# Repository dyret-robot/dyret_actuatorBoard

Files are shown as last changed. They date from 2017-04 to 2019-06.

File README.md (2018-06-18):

# `dyret_actuatorBoard`
   

This repository contains the code and PCB design of the `dyret_actuatorBoard`.

## Documentation
For further documentation check out the
[wiki](https://github.com/dyret-robot/dyret_documentation/wiki).

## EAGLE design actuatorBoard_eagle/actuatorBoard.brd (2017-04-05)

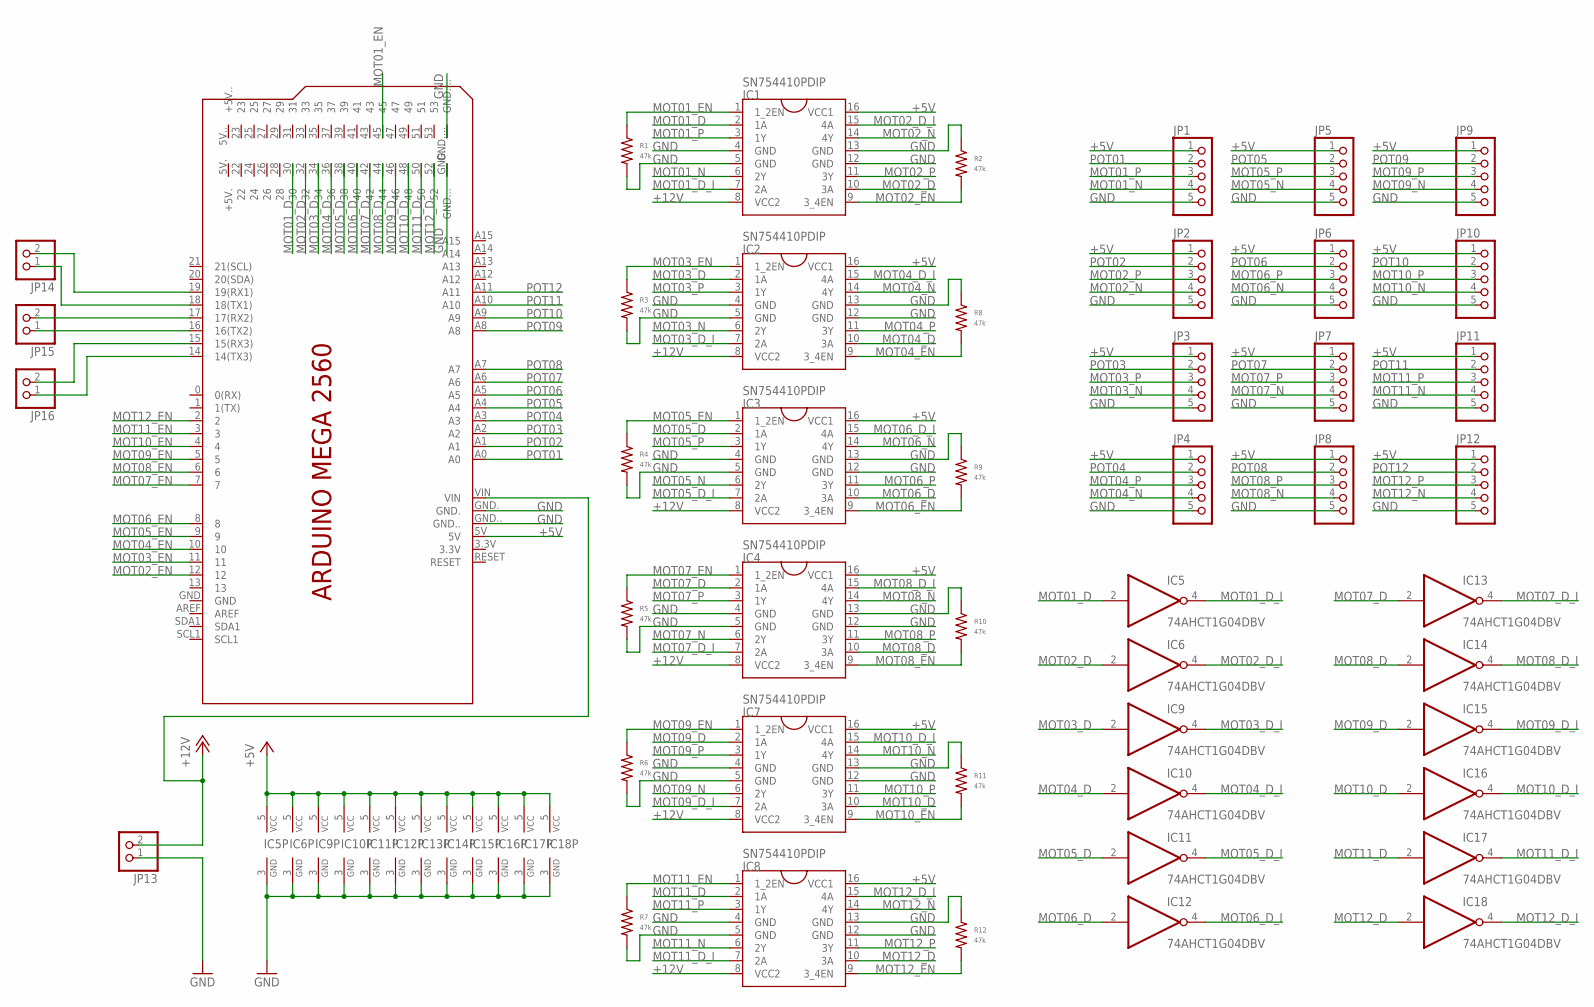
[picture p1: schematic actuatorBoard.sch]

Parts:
IC1, IC2, IC3, IC4, IC7, IC8: SN754410PDIP; DIL16
IC5, IC6, IC9, IC10, IC11, IC12, IC13, IC14, IC15, IC16, IC17, IC18: 74AHCT1G04DBV; SOT23-5
JP1, JP2, JP3, JP4, JP5, JP6, JP7, JP8, JP9, JP10, JP11, JP12: PINHD-1X5; 1X05
JP13, JP14, JP15, JP16: PINHD-1X2; 1X02
PCB1: ARDUINO_MEGA2560
R1, R2, R3, R4, R5, R6, R7, R8, R9, R10, R11, R12: 47k; R0603

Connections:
+5V: IC1.16 (VCC1), IC2.16 (VCC1), IC3.16 (VCC1), IC4.16 (VCC1), IC5.5 (VCC), IC6.5 (VCC), IC7.16 (VCC1), IC8.16 (VCC1), IC9.5 (VCC), IC10.5 (VCC), IC11.5 (VCC), IC12.5 (VCC), IC13.5 (VCC), IC14.5 (VCC), IC15.5 (VCC), IC16.5 (VCC), IC17.5 (VCC), IC18.5 (VCC), JP1.1, JP2.1, JP3.1, JP4.1, JP5.1, JP6.1, JP7.1, JP8.1, JP9.1, JP10.1, JP11.1, JP12.1, PCB1.5V
+12V: IC1.8 (VCC2), IC2.8 (VCC2), IC3.8 (VCC2), IC4.8 (VCC2), IC7.8 (VCC2), IC8.8 (VCC2), JP13.2, PCB1.VIN
GND: IC1.4 (GND), IC1.5 (GND), IC1.12 (GND), IC1.13 (GND), IC2.4 (GND), IC2.5 (GND), IC2.12 (GND), IC2.13 (GND), IC3.4 (GND), IC3.5 (GND), IC3.12 (GND), IC3.13 (GND), IC4.4 (GND), IC4.5 (GND), IC4.12 (GND), IC4.13 (GND), IC5.3 (GND), IC6.3 (GND), IC7.4 (GND), IC7.5 (GND), IC7.12 (GND), IC7.13 (GND), IC8.4 (GND), IC8.5 (GND), IC8.12 (GND), IC8.13 (GND), IC9.3 (GND), IC10.3 (GND), IC11.3 (GND), IC12.3 (GND), IC13.3 (GND), IC14.3 (GND), IC15.3 (GND), IC16.3 (GND), IC17.3 (GND), IC18.3 (GND), JP1.5, JP2.5, JP3.5, JP4.5, JP5.5, JP6.5, JP7.5, JP8.5, JP9.5, JP10.5, JP11.5, JP12.5, JP13.1, PCB1.GND., PCB1.GND.., PCB1.GND..., PCB1.GND...., R1.P$2, R2.P$1, R3.P$2, R4.P$2, R5.P$2, R6.P$2, R7.P$2, R8.P$1, R9.P$1, R10.P$1, R11.P$1, R12.P$1
MOT01_D: IC1.2 (1A), IC5.2 (I), PCB1.30
MOT01_D_I: IC1.7 (2A), IC5.4 (O)
MOT01_EN: IC1.1 (1_2EN), PCB1.45, R1.P$1
MOT01_N: IC1.6 (2Y), JP1.4
MOT01_P: IC1.3 (1Y), JP1.3
MOT02_D: IC1.10 (3A), IC6.2 (I), PCB1.32
MOT02_D_I: IC1.15 (4A), IC6.4 (O)
MOT02_EN: IC1.9 (3_4EN), PCB1.12, R2.P$2
MOT02_N: IC1.14 (4Y), JP2.4
MOT02_P: IC1.11 (3Y), JP2.3
MOT03_D: IC2.2 (1A), IC9.2 (I), PCB1.34
MOT03_D_I: IC2.7 (2A), IC9.4 (O)
MOT03_EN: IC2.1 (1_2EN), PCB1.11, R3.P$1
MOT03_N: IC2.6 (2Y), JP3.4
MOT03_P: IC2.3 (1Y), JP3.3
MOT04_D: IC2.10 (3A), IC10.2 (I), PCB1.36
MOT04_D_I: IC2.15 (4A), IC10.4 (O)
MOT04_EN: IC2.9 (3_4EN), PCB1.10, R8.P$2
MOT04_N: IC2.14 (4Y), JP4.4
MOT04_P: IC2.11 (3Y), JP4.3
MOT05_D: IC3.2 (1A), IC11.2 (I), PCB1.38
MOT05_D_I: IC3.7 (2A), IC11.4 (O)
MOT05_EN: IC3.1 (1_2EN), PCB1.9, R4.P$1
MOT05_N: IC3.6 (2Y), JP5.4
MOT05_P: IC3.3 (1Y), JP5.3
MOT06_D: IC3.10 (3A), IC12.2 (I), PCB1.40
MOT06_D_I: IC3.15 (4A), IC12.4 (O)
MOT06_EN: IC3.9 (3_4EN), PCB1.8, R9.P$2
MOT06_N: IC3.14 (4Y), JP6.4
MOT06_P: IC3.11 (3Y), JP6.3
MOT07_D: IC4.2 (1A), IC13.2 (I), PCB1.42
MOT07_D_I: IC4.7 (2A), IC13.4 (O)
MOT07_EN: IC4.1 (1_2EN), PCB1.7, R5.P$1
MOT07_N: IC4.6 (2Y), JP7.4
MOT07_P: IC4.3 (1Y), JP7.3
MOT08_D: IC4.10 (3A), IC14.2 (I), PCB1.44
MOT08_D_I: IC4.15 (4A), IC14.4 (O)
MOT08_EN: IC4.9 (3_4EN), PCB1.6, R10.P$2
MOT08_N: IC4.14 (4Y), JP8.4
MOT08_P: IC4.11 (3Y), JP8.3
MOT09_D: IC7.2 (1A), IC15.2 (I), PCB1.46
MOT09_D_I: IC7.7 (2A), IC15.4 (O)
MOT09_EN: IC7.1 (1_2EN), PCB1.5, R6.P$1
MOT09_N: IC7.6 (2Y), JP9.4
MOT09_P: IC7.3 (1Y), JP9.3
MOT10_D: IC7.10 (3A), IC16.2 (I), PCB1.48
MOT10_D_I: IC7.15 (4A), IC16.4 (O)
MOT10_EN: IC7.9 (3_4EN), PCB1.4, R11.P$2
MOT10_N: IC7.14 (4Y), JP10.4
MOT10_P: IC7.11 (3Y), JP10.3
MOT11_D: IC8.2 (1A), IC17.2 (I), PCB1.50
MOT11_D_I: IC8.7 (2A), IC17.4 (O)
MOT11_EN: IC8.1 (1_2EN), PCB1.3, R7.P$1
MOT11_N: IC8.6 (2Y), JP11.4
MOT11_P: IC8.3 (1Y), JP11.3
MOT12_D: IC8.10 (3A), IC18.2 (I), PCB1.52
MOT12_D_I: IC8.15 (4A), IC18.4 (O)
MOT12_EN: IC8.9 (3_4EN), PCB1.2, R12.P$2
MOT12_N: IC8.14 (4Y), JP12.4
MOT12_P: IC8.11 (3Y), JP12.3
unnamed: JP15.2, PCB1.17 (17(RX2))
unnamed: JP15.1, PCB1.16 (16(TX2))
unnamed: JP14.1, PCB1.18 (18(TX1))
unnamed: JP14.2, PCB1.19 (19(RX1))
unnamed: JP16.2, PCB1.15 (15(RX3))
unnamed: JP16.1, PCB1.14 (14(TX3))
POT01: JP1.2, PCB1.A0
POT02: JP2.2, PCB1.A1
POT03: JP3.2, PCB1.A2
POT04: JP4.2, PCB1.A3
POT05: JP5.2, PCB1.A4
POT06: JP6.2, PCB1.A5
POT07: JP7.2, PCB1.A6
POT08: JP8.2, PCB1.A7
POT09: JP9.2, PCB1.A8
POT10: JP10.2, PCB1.A9
POT11: JP11.2, PCB1.A10
POT12: JP12.2, PCB1.A11

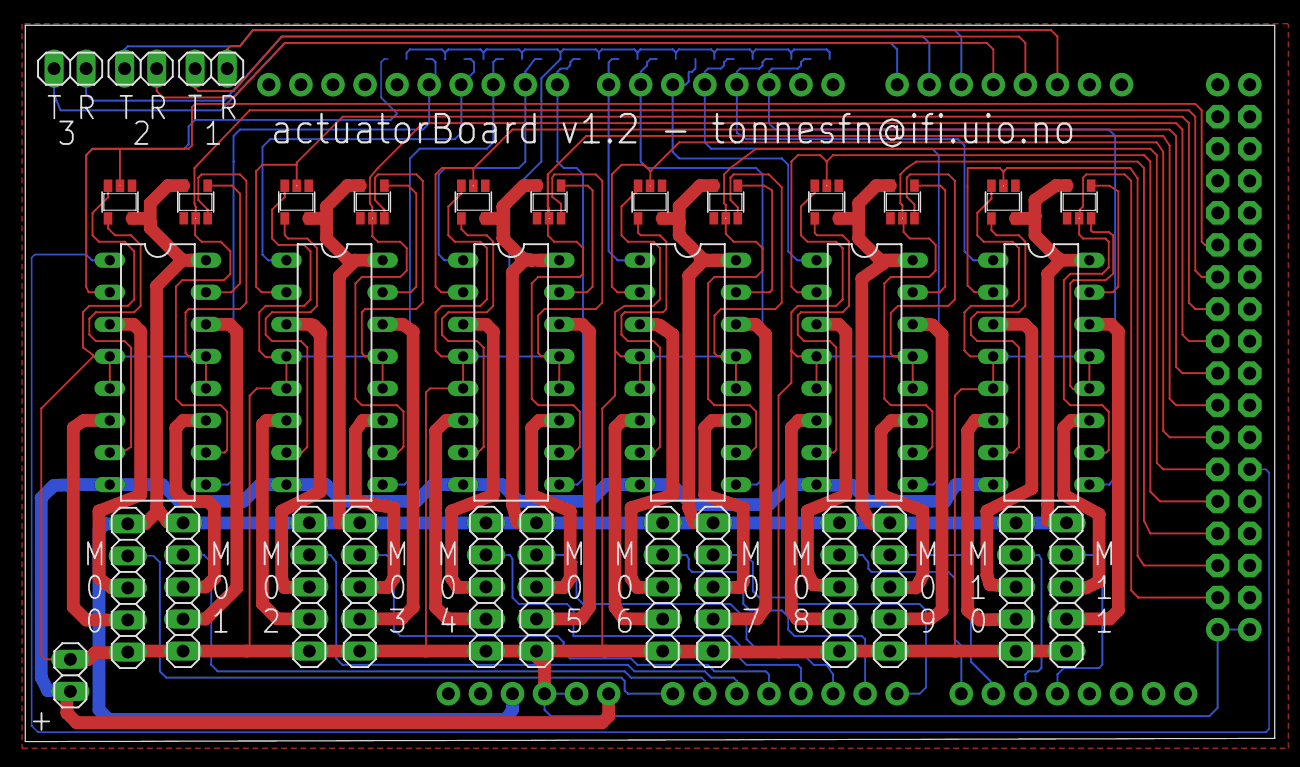
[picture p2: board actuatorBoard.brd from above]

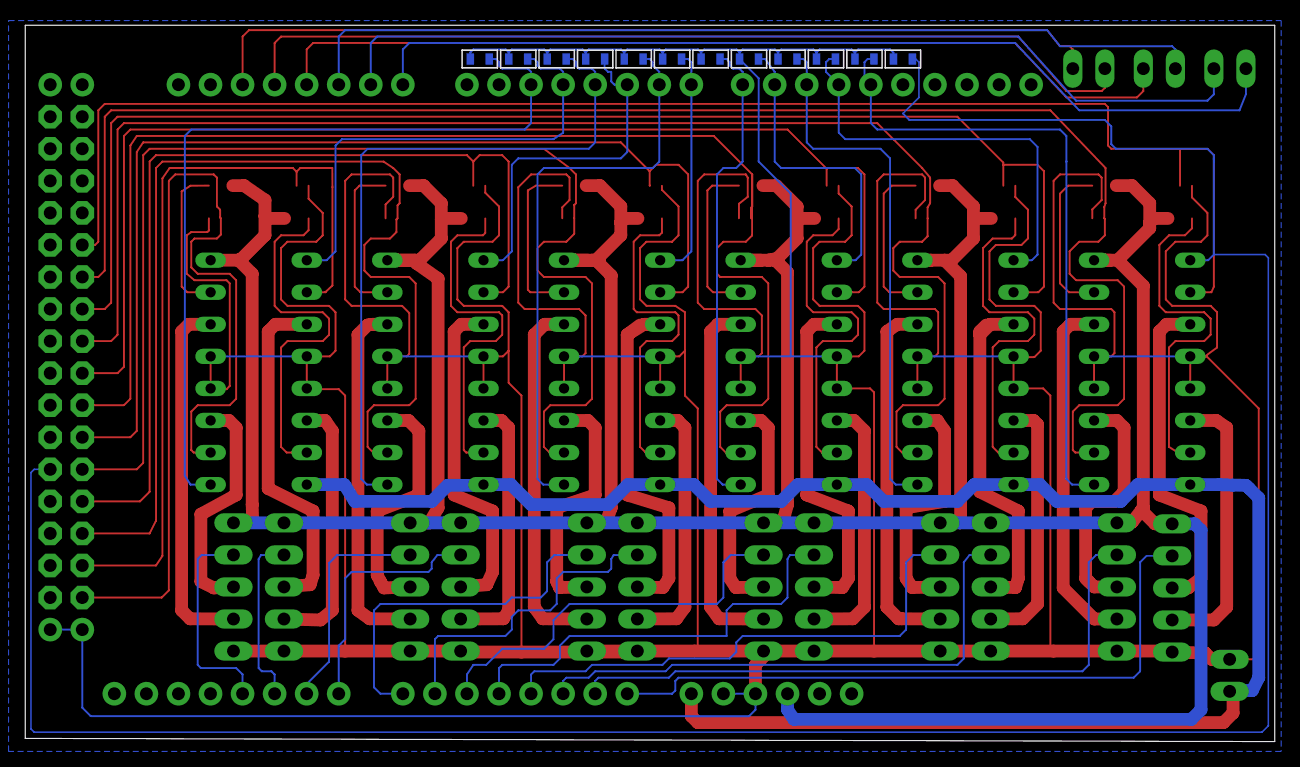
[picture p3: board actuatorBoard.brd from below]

Board: 2 copper layers, 99.0 x 56.8 mm, 47 parts (12 on the bottom side), 81 nets.

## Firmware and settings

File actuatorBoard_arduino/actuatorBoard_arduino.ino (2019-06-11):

#include <ros.h>
#include <dyret_hardware/ActuatorBoardCommand.h>
#include <dyret_hardware/ActuatorBoardState.h>
#include <std_msgs/String.h>

const int actuatorEnablePins[]    = {11, 10,  7,  6,  5,  4,  3,  2};
const int actuatorDirectionPins[] = {34, 36, 42, 44, 46, 48, 50, 52};
const int limitSwitchInputPins[]  = {25, 29, 33, 37, 41, 45, 49, 53};
const int limitSwitchOutputPins[] = {23, 27, 31, 35, 39, 43, 47, 51};
const int encoderInputPins[]      = { 2,  3,  6,  7,  8,  9, 10, 11};

const int pValue = 500;

unsigned long sendMessagePreviousms = 0;
const int sendMessageIntervalms = 100; // 10hz
unsigned long motorControlPreviousms = 0;
const int motorControlIntervalms = 10; // 100hz
unsigned long errorDetectionPreviousms = 0;
const int errorDetectionIntervalms = 2000; // 2hz

const int femurLengthLimit = 50;
const int tibiaLengthLimit = 95;

bool initiated[8];

bool commandReceived[8];

float actuatorGoal[8];

float lastPos[8]; // Last recorded position, used to detect stuck motors or faulty encoders
bool currentlyRunning[8];
bool motorError[8];
float currentPos[8]; // Current position in MM

int lastMeasurement[8];
int turnCounter[8];

unsigned motorPwm[8];

int zeroOffset[8]; // Contains the offset when zero

ros::NodeHandle nh;

dyret_hardware::ActuatorBoardState stateMessage;
ros::Publisher statePub("dyret/actuator_board/state", &stateMessage);

void messageCb(const dyret_hardware::ActuatorBoardCommand& msg);
ros::Subscriber<dyret_hardware::ActuatorBoardCommand> s("dyret/actuator_board/command", messageCb);

bool limitSwitchActive(int givenActuatorNumber) {
  if (digitalRead(limitSwitchInputPins[givenActuatorNumber]) == LOW) return false;
  return true;
}

void expandActuator(int givenActuatorNumber) {
  digitalWrite(actuatorDirectionPins[givenActuatorNumber], LOW); // Set direction
  digitalWrite(actuatorEnablePins[givenActuatorNumber], HIGH); // Set enable bit
}

void retractActuator(int givenActuatorNumber) {
  digitalWrite(actuatorDirectionPins[givenActuatorNumber], HIGH); // Set direction
  digitalWrite(actuatorEnablePins[givenActuatorNumber], HIGH); // Set enable bit
}

void disableMotor(int givenActuatorNumber) {
  motorPwm[givenActuatorNumber] = 0;
  digitalWrite(actuatorEnablePins[givenActuatorNumber], LOW); // Set enable bit
}

int readRawEncoder(int givenActuatorNumber) { // Returns int 0-1023
  return analogRead(encoderInputPins[givenActuatorNumber]);
}

void setMotorZeroPoint(int givenActuatorNumber) {
  initiated[givenActuatorNumber] = true;
  commandReceived[givenActuatorNumber] = false;
  actuatorGoal[givenActuatorNumber] = 0.0;
  zeroOffset[givenActuatorNumber] = readRawEncoder(givenActuatorNumber);
  turnCounter[givenActuatorNumber] = 0;
}

void enableMotor(int givenActuatorNumber, int givenMotorSpeed, bool motorDirectionRetract) { // Speed 0-255, direction inward
  //int motorSpeed = min(givenMotorSpeed, 180); // 255 = 14.8V, 180 ~= 12V
  int motorSpeed = givenMotorSpeed; // For 12V operation

  // Set direction
  if (motorDirectionRetract) {
    digitalWrite(actuatorDirectionPins[givenActuatorNumber], HIGH); // Set direction
  } else {
    digitalWrite(actuatorDirectionPins[givenActuatorNumber], LOW); // Set direction
  }

  // Set speed (motor enable)
  analogWrite(actuatorEnablePins[givenActuatorNumber], motorSpeed);

}

void readPositions() {

  int measurements[8];

  // Read from encoders
  for (int i = 0; i < 8; i++) {
    measurements[i] = readRawEncoder(i);
  }

  // Handle turncounter
  for (int i = 0; i < 8; i++) {
    // Overflowed:
    if ((measurements[i] < 256) && (lastMeasurement[i] > 768)) {
      turnCounter[i]++;
    }

    // Underflowed:
    if ((measurements[i] > 768) && (lastMeasurement[i] < 256)) {
      turnCounter[i]--;
    }

    lastMeasurement[i] = measurements[i];
  }

  // Convert to mm
  for (int i = 0; i < 8; i++) {
    currentPos[i] = -((measurements[i] + (turnCounter[i] * 1024.0)) - zeroOffset[i]) * ((16.0 / 7.0) / 1024.0);
  }
}

void setupStateMessage() {

  for (int i = 0; i < 8; i++) {
    stateMessage.position[i] = currentPos[i];
    stateMessage.raw[i] = lastMeasurement[i];
    stateMessage.pwm[i] = motorPwm[i];

    if (motorError[i] == false && initiated[i] == true && commandReceived[i] == true) {
      stateMessage.status[i] = stateMessage.STATUS_RUNNING;
    } else if (motorError[i] == false) {
      stateMessage.status[i] = stateMessage.STATUS_RESTING;
    } else {
      stateMessage.status[i] = stateMessage.STATUS_ERROR;
    }
  }
}

void homeActuators() {
  for (int i = 0; i < 8; i++) {
    initiated[i] = false;
    currentlyRunning[i] = false;
    motorError[i] = false;
  }

  for (int i = 0; i < 8; i++) {
    commandReceived[i] = true;
    actuatorGoal[i] = -100;
  }

  for (int i = 0; i < 8; i++) {
    lastMeasurement[i] = readRawEncoder(i);
  }
}

void messageCb(const dyret_hardware::ActuatorBoardCommand& msg) {

  if (msg.length_length == 1) { // Special case for just one distance without ids
    if (msg.length[0] < 0) { // Zero actuators if receiving negative number
      homeActuators();
    } else {
      for (int i = 0; i < 8; i = i + 2) {
        if (initiated[i] == true) actuatorGoal[i] = min(msg.length[0], femurLengthLimit);
        commandReceived[i] = true;
      }

      for (int i = 1; i < 8; i = i + 2) {
        if (initiated[i] == true) actuatorGoal[i] = min(msg.length[0], tibiaLengthLimit);
        commandReceived[i] = true;
      }
    }
  } else if (msg.length_length == 2) { // Special case for just two distances without ids
    for (int i = 0; i < 8; i = i + 2) {
      if (initiated[i] == true) actuatorGoal[i] = min(msg.length[0], femurLengthLimit);
      commandReceived[i] = true;
    }

    for (int i = 1; i < 8; i = i + 2) {
      if (initiated[i] == true) actuatorGoal[i] = min(msg.length[1], tibiaLengthLimit);
      commandReceived[i] = true;
    }
  } else if (msg.length_length == 8) {
    for (int i = 0; i < 8; i = i + 2) {
      if (initiated[i] == true) actuatorGoal[i] = min(msg.length[i], femurLengthLimit);
      commandReceived[i] = true;
    }

    for (int i = 1; i < 8; i = i + 2) {
      if (initiated[i] == true) actuatorGoal[i] = min(msg.length[i], tibiaLengthLimit);
      commandReceived[i] = true;
    }
  }

  // Reset all motor errors on new command
  for (int i = 0; i < 8; i++){
    motorError[i] = false;
  }

}

void setup() {
  for (int i = 0; i < 8; i++) {
    actuatorGoal[i] = 512.0;
    motorPwm[i] = 0;
    zeroOffset[i] = 0;
    turnCounter[i] = 0;
    commandReceived[i] = false;
    initiated[i] = false;
    currentlyRunning[i] = false;
    motorError[i] = false;
  }

  for (int i = 0; i < sizeof(actuatorEnablePins) / sizeof(int); i++) {
    pinMode(actuatorEnablePins[i], OUTPUT);  // Enable pins
    digitalWrite(actuatorEnablePins[i], LOW);
  }
  for (int i = 0; i < sizeof(actuatorDirectionPins) / sizeof(int); i++) {
    pinMode(actuatorDirectionPins[i], OUTPUT);  // Direction pins
  }
  for (int i = 0; i < sizeof(limitSwitchOutputPins) / sizeof(int); i++) {
    pinMode(limitSwitchOutputPins[i], OUTPUT);  // Set pinmode and output ground to limit switch outputs
    digitalWrite(limitSwitchOutputPins[i], LOW);
  }
  for (int i = 0; i < sizeof(limitSwitchInputPins) / sizeof(int); i++) {
    pinMode(limitSwitchInputPins[i], INPUT);  // Set pinmode and connect pullup to limit switch inputs
    digitalWrite(limitSwitchInputPins[i], HIGH);
  }

  nh.initNode();

  homeActuators();

  nh.subscribe(s);
  nh.advertise(statePub);

}

void loop() {

  // Read positions:
  readPositions();

  // Send messages:
  unsigned long currentMillis = millis();

  if (currentMillis - sendMessagePreviousms >= sendMessageIntervalms) {
    sendMessagePreviousms = currentMillis;

    setupStateMessage();

    statePub.publish(&stateMessage);

  }

  // Do motor loop:
  currentMillis = millis();

  if (currentMillis - motorControlPreviousms >= motorControlIntervalms) {
    motorControlPreviousms = currentMillis;
    for (int i = 0; i < 8; i++) {

      if (commandReceived[i] == true && motorError[i] == false) {

        int motorSpeed = min(abs(actuatorGoal[i] - currentPos[i]) * pValue, 255);
        motorPwm[i] = motorSpeed;

        if (abs(actuatorGoal[i] - currentPos[i]) < 0.25) { // 0.25mm accuracy
          disableMotor(i);
          commandReceived[i] = false;
        } else {
          if (currentPos[i] > actuatorGoal[i]) { // Retract
            if (limitSwitchActive(i) == false) {
              enableMotor(i, motorSpeed, true);
            } else {
              setMotorZeroPoint(i);
              motorPwm[i] = 0;
            }

          } else {
            enableMotor(i, motorSpeed, false);
          }

        }

      } else {
        disableMotor(i);
      }
    }
  }

  // Detect stuck motors:
  currentMillis = millis();

  if (currentMillis - errorDetectionPreviousms >= errorDetectionIntervalms) {
    errorDetectionPreviousms = currentMillis;

    for (int i = 0; i < 8; i++) {
      if (currentlyRunning[i] && motorPwm[i] == 255) { // It has been running continously for a period
        if (abs(lastPos[i] - currentPos[i]) < 0.1) { // It has moved less than 0.1mm, even though it is enabled
          disableMotor(i);
          motorError[i] = true;
        }
      }

      // Record status for next loop:
      if (motorPwm[i] == 255) {
        currentlyRunning[i] = true;
      } else {
        currentlyRunning[i] = false;
      }
      lastPos[i] = currentPos[i];
    }

  }

  // Spin ROS:
  nh.spinOnce();

}

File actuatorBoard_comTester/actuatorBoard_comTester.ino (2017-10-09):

#include <ros.h>
#include <dyret_common/Configuration.h>
#include <std_msgs/String.h>

ros::NodeHandle nh;

dyret_common::Configuration stateMessage;
ros::Publisher statePub("actuatorStates", &stateMessage);

dyret_common::Configuration debugMessage;
ros::Publisher debugPub("dyret_actuator/actuatorDebug", &stateMessage);

void messageCb(const dyret_common::Configuration& msg){
/*  debugMessage.id = msg.id;
  debugMessage.id_length = msg.id_length;
  debugMessage.distance = msg.distance;
  debugMessage.distance_length = msg.distance_length;
*/
  debugMessage = msg;

  debugPub.publish(&debugMessage);
}

ros::Subscriber<dyret_common::Configuration> s("actuatorCommands",messageCb);

void setup() {
  nh.initNode(); 
  
  nh.subscribe(s);
  nh.advertise(statePub);
  nh.advertise(debugPub);

}

void loop() {
  
  nh.spinOnce();

}

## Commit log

2017-10-05 Added actuatorBoard_arduinoTester
2017-10-05 Added pin definitions
2017-10-05 Fixed error in position calculation
    [actuatorBoard_arduino.ino]
2017-10-05 Slightly improved reset of actuators to return to sensed 0 pos
    [actuatorBoard_arduino.ino]
2017-10-10 Added interval execution of message sending and motor control
2017-10-10 Fixed formating and message setup functions
    [actuatorBoard_arduino.ino]
2017-10-10 Removed separate leg zeroing function
2017-10-13 Added two special cases for controlling all actuators
2017-10-30 Added support for 15V operation of board
2017-12-07 Added blocking while zeroing legs
2018-06-01 Iteration on actuatorBoard
    [actuatorBoard.brd, actuatorBoard.sch]
2019-06-11 Added error detection for stuck motors
    [actuatorBoard_arduino.ino]
2019-06-11 Added reset of error on new command
    [actuatorBoard_arduino.ino]

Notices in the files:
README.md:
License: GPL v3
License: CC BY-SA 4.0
